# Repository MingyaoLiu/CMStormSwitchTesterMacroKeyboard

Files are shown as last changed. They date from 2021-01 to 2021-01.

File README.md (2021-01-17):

# CMStormSwitchTesterMacroKeyboard

Convert a CMStorm (CoolerMaster) Key Switch Tester into a macro keyboard using an Arduino Pro Micro.

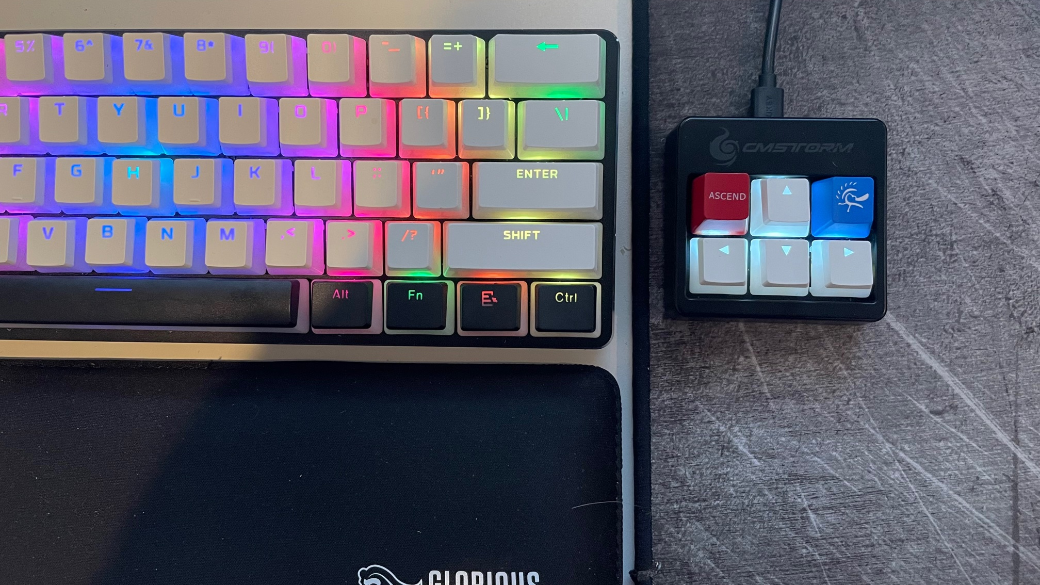
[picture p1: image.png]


## Hardware

My GMMK has a very awkward arrow key set up, and there is no way to change FN key map for me to use the bottom right 4 key for arrow key.

I was thinking how I could get arrow key, then I remembered I had a CMStorm key switch tester from massdrop, and why not just build a keyboard from it?

I looked up what I would need, for a control board my mind went to arduino from the start, turns out sparkfun made a tiny micro usb version of Leonardo with ATmega32u4 called sparkfun pro micro, with USB keyboard HID native support. What a god sent.

Size wise it is basically perfect. The CMStorm key switch tester has 4 plastic pillar inside for support, but they must have last minute changed the switch mount plate to steel, so the 4 support is absolutely useless (not a mechanical engineer, don't quote me on this).

Cut them off with a plier, drill hole on the center back of the inner case, slightly cut off part of the outter case, micro usb port fit right in.

I decided to have the pro micro face down in the case, to lower the micro usb port, and better prevent shorting. Use hot glue to secure the pro micro inside the case after you done all the wire run.

For the switches I bent the copper feet just a little bit, because the copper feet is actually taller than the plastic shell. And for each switch, 1 of the feet is always softer than the other, I used the softer feet for ground, and harder feet for data pin (again not an electrical engineer, someone correct me).

I coated all naked wire and solder joint with nail polisher twice after i finished soldering, special thank to Rosy for the nail polisher. I dried it making sure the switches are facing upwards, so no nail polish could drip inside the switch while drying.

LED hot glued to be more secure, but the inside is quite tight with all the wires jamming together, so no chance of moving at all. Be careful with hot glue might stick out and cause clearance issue inside the case. (mostly between the led and the pro micro)

Be careful the switch is not pushed with too much force inside, it could pop out. the clearance is quite good just be aware because once you closed the case, it's hard to open again.

## Software

I took some inspiration from a template someone shared on the internet. However the template doesn't have many of the feature I wanted, for example holding a right arrow key should be able to make it travel continuously, and led control is not there.

My code support:
1. Assign key to each button
2. Long press will register key press continuously after a second or so
3. Press top left and top right key together will toggle LED
4. LED time out after 10 mins
5. LED on/off default status is saved to EEPROM

Arduino file contains detailed commenting, please read before use.

LED timer unsigned long may overflow after you left it on for 100 days or so, but in theory the overflow will not cause any issue and it will be reseted to 0 after overflow.

## Schema

Schema draw on fritzing, button is the switch.

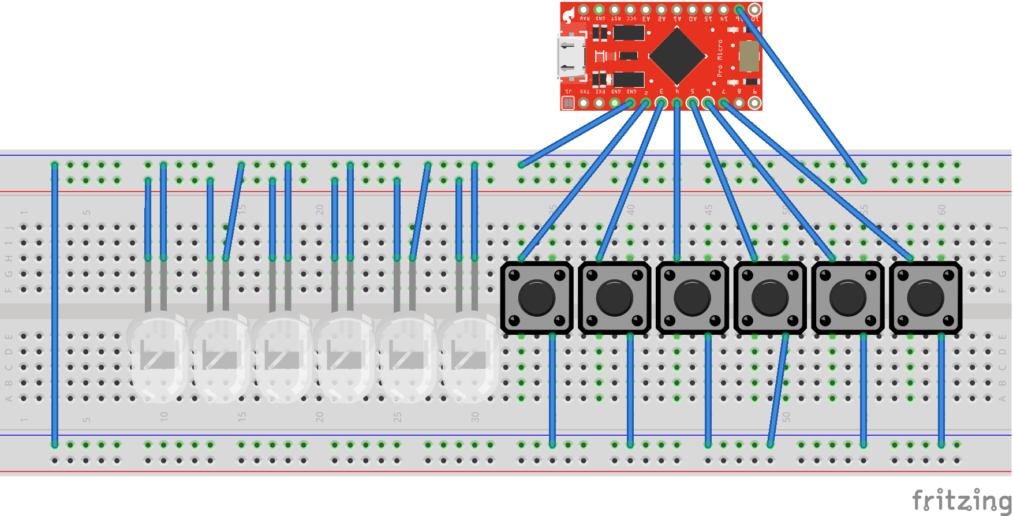
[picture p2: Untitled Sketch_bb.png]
schema


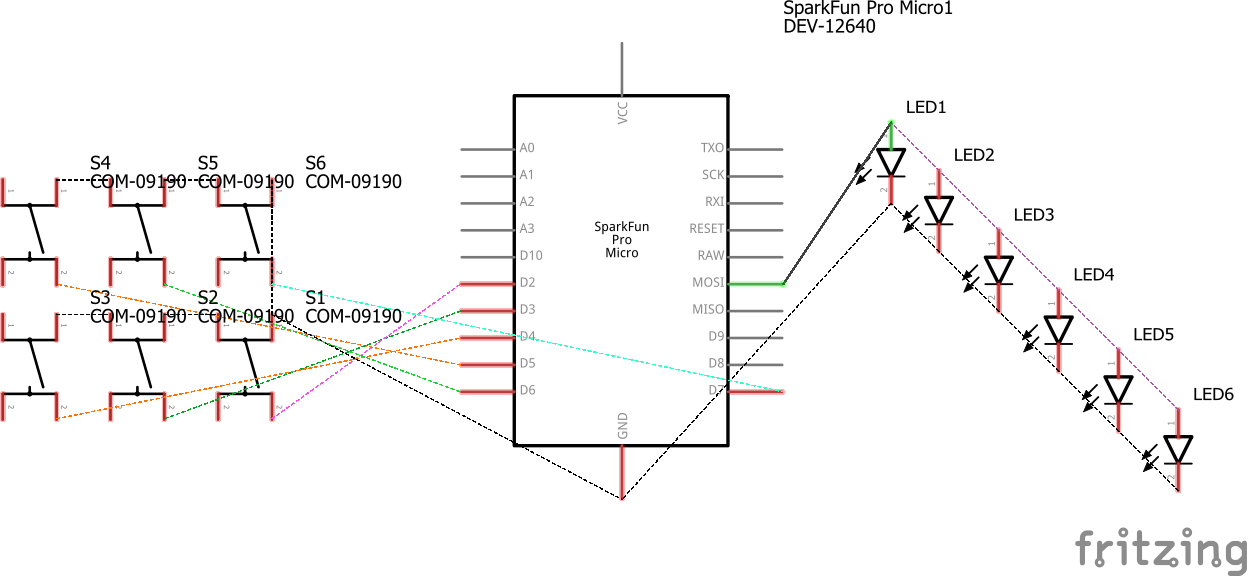
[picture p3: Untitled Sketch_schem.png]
schema2


## BOM

Arduino Pro Micro -------------- $7 CAD

Key Switch x6 ------------------ $6 CAD

Key cap x6 --------------------- $6 CAD

CMStorm Switch Tester ---------- $20 CAD (comes with switch and translucent cap)

Total -------------------------- $27 CAD + ($12 CAD - cap&switch)

## After thought

This is one successful project. What I would improve next time:
1. Better soldering. Wasn't so mindful when doing it, i was on call with my mom and getting criticized for holding my soldering iron like chopstick every 30 seconds. End up burnt a hole in my mousepad too.
2. Run WS2812B led strip inside the case instead of led bulb. led bulb is too big, and individual address will require 6 more wire which is just clutter hell inside the case. In comparison, WS2812B can be individually addressed and only need 3 wires and a resistor. Based on my measurement, the 60 LED/m WS2812B strip should have the led exactly match the position of the switch, making it a no brainer. I don't have any 5V strip on hand that's why I couldn't do it. I have ordered some 5v 5M 5050SMD WS2812B 300LED strip for my next project. 30 bucks for 5m.
3. better wiring. I would get maget wires, they are thin, easy to burn off part of the shell, and non conductive. But i didn't have any, I'm ordering some NOW.
4. USB-C. I really want USB-C, but couldn't find any cheap board with it. The pro micro I got from amazon are chinese clones of sparkfun, 22 bucks for 3. (again canadian dollar). The sparkfun USB-C version of this is 30 CAD for 1.
5. QMK firmware. There should be something that can be done with QMK.
6. Just buy from aliexpress. new one with the same feature are around 25 CAD.

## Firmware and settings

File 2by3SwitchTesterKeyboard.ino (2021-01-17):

// 2 x 3 macro keyboard converted from CMStorm Switch tester.
#include <EEPROM.h>
#include "Keyboard.h"

/**
   Pin Key map:
   2 - bottom right key  - Right Arrow
   3 - bottom center key - Down Arrow
   4 - bottom left key   - Left Arrow
   5 - top left key      - Page Up
   6 - top center key    - Up Arrow
   7 - top right key     - Page Down
   16 - LED 5v output
*/

const int num_of_key = 6;
uint8_t switch_pin[num_of_key] = { 2, 3, 4, 5, 6, 7 }; // arduino pin of switch.
char switch_key[num_of_key] = { (char)0xD7, (char) 0xD9, (char) 0xD8, (char) 0xD3, (char) 0xDA, (char)0xD6 }; // keyboard char of switch, map pin index.
uint8_t switch_reading[num_of_key]; // reading of 1 is up, reading of 0 is down
bool press_these[num_of_key];
bool switch_is_down[num_of_key];
uint8_t switch_down_count[num_of_key]; // switch continuous down state count.
int minimum_hold_down_loop_count = 20; // how long to hold until register continously.
int led_pin = 16; // LED 5v pin
unsigned long last_input_received = millis(); // last input recieved millsecond.
unsigned long led_time_out_milsec = 600000; // 10 mins then led will turn off automatically
int default_led_status = 1; // default led status (on by default).
int key_press_delay = 30;
int key_release_end_delay = 10;

void setup() {

  pinMode(led_pin, OUTPUT);
  int led_stored_val = EEPROM.read(0); // read EEPROM 0 value. this address is used for LED on off setting.
  if (led_stored_val != 0 && led_stored_val != 1) { // check if EEPROM 0 doesn't have valid value, write default (on).
    EEPROM.write(0, default_led_status);
  } else {
    default_led_status = led_stored_val; // load EEPROM 0 value to default_led_status
  }
  digitalWrite(led_pin, default_led_status);
  for (uint8_t i = 0; i < num_of_key; i++) { // Set all button pin state.
    pinMode(switch_pin[i], INPUT_PULLUP);
  }
  Keyboard.begin();
}

void loop() {
  for (uint8_t i = 0; i < num_of_key; i++) {
    switch_reading[i] = digitalRead(switch_pin[i]);
    press_these[i] = false;
    if (switch_reading[i] == 0 && !switch_is_down[i]) { // Button is now pressed down, and it was up before, add to press list.
      switch_is_down[i] = true;
      press_these[i] = true;
    } else if (switch_reading[i] == 1 && switch_is_down[i]) { // Button is now up, and it was down before, reset down and down status count.
      switch_is_down[i] = false;
      switch_down_count[i] = 0;
    } else if (switch_reading[i] == 0 && switch_is_down[i]) { // button is down, and it is holding down since before.
      if (switch_down_count[i] > minimum_hold_down_loop_count) { // if its been n loop of down state, hold down state and output.
        press_these[i] = true;
      } else { // button hasn't hold long enough to continue register, up continuous state and not output yet.
        switch_down_count[i] += 1;
      }
    }
  }
  if (press_these[3] && press_these[5]) { // If button on top left and top right are pressed together, then toggle default LED lighting
    if (switch_down_count[3] == 0 || switch_down_count[5] == 0 ) { // Make sure the led status only switch once even if holding the two ket forever.
      default_led_status = default_led_status ? 0 : 1;
      EEPROM.write(0, default_led_status);
    }
  } else {
    for (uint8_t i = 0; i < num_of_key; i++) { // press each key that's in the press_these list.
      if (press_these[i]) {
        last_input_received = millis(); // update last input received timer.
        Keyboard.press(switch_key[i]);
      }
    }
    if ((millis() - last_input_received) >= led_time_out_milsec) { // if there hasn't been a key press in led_time_out_milsec.
      digitalWrite(led_pin, LOW);
    } else {
      digitalWrite(led_pin, default_led_status);
    }
    delay(key_press_delay);

    for (uint8_t i = 0; i < num_of_key; i++) { // release each key in the press_these list.
      if (press_these[i]) {
        Keyboard.release(switch_key[i]);
      }
    }
    delay(key_release_end_delay);
  }
}
